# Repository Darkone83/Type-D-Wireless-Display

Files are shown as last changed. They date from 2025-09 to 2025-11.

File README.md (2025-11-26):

# Type-D Wireless Display

<div align=center>
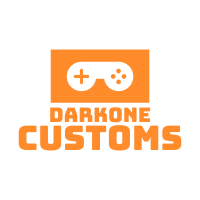
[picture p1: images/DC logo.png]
  
  
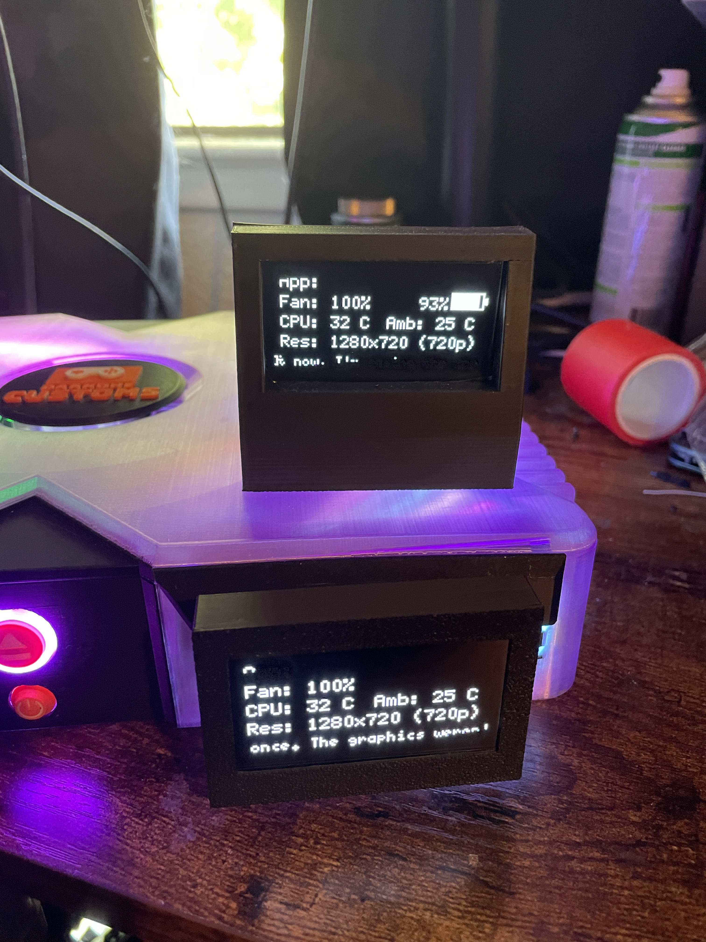
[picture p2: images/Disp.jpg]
  
</div>



A tiny OLED “status screen” for original Xbox setups (and other sources), driven over Wi‑Fi/UDP.  
Shows a main system summary, a dense second page, a health page, and an optional weather page, and insignia leaderboard page.
Designed for the Waveshare 2.42″ SSD1309 I²C panel (128×64), with added experimental support for US2066 OLED displays.
A Type D Expansion unit is required for these displays to properly work and display data. See more info <a href="https://github.com/Darkone83/Type-D/tree/main/EXP%20Src">Here</a>. To display the App name, the XBMC4Gamers script for the Type D Expansion unit is required.

---

## ✨ Features

- **Four screens** that auto-rotate:
  - **MAIN** – App name, fan %, CPU °C, ambient °C. Battery widget appears if a LC709203F fuel gauge is found.
  - **SECOND** – Tray state, AV type, encoder chip, guessed Xbox version, serial, MAC, region.
  - **HEALTH** – Wi‑Fi RSSI (with quality label), free heap, IP address.
  - **WEATHER** *(optional)* – Location header, big temp, condition text, humidity & wind.
  - **INSIGNIA** - Will display insignia leaderboard info when a compatible game is selected.
- **Inactivity policy (no “STALE”)**
  - Before any UDP data: full-screen boot logo only.
  - No UDP for **2 min**: show boot logo.
  - No UDP for **5 min**: bouncing “Sleeping…” screensaver.
  - Any UDP packet instantly cancels saver and resumes the carousel.
- **Smooth transitions** – slide-in left/right between screens.
- **Quote ticker** on MAIN with periodic rotation.
- **Web setup portal** (captive portal) for Wi‑Fi + Weather settings.
- **mDNS**: `http://typeddisp.local/` (when joined to your LAN).

---

## 📱 Get the App

Download on the App Store (https://apps.apple.com/us/app/type-d-viewer/id6755620952)

Download the **Type D Viewer** app for iOS to view live telemetry data from your XBOX.

---

## 🧰 Required Hardware

### Desktop build
- **ESP32‑S3**: Waveshare ESP32-S3 Zero or compatable. <a href="https://www.aliexpress.us/item/3256808233319699.html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">AliExpress (Clone)</a>, <a href="https://www.amazon.com/dp/B0CHYHGYRH?th=1">Amazon</a>.
- **Waveshare 2.42″ OLED**. <a href="https://www.waveshare.com/2.42inch-oled-module.htm">WaveShare</a>, <a href="https://www.amazon.com/dp/B0CM3RHMGP">Amazon</a>.
- *(Optional)* **LC709203F** fuel gauge (Adafruit breakout works great). <a href="https://www.adafruit.com/product/4712">Adafruit</a>.
- *(Optional)* LiPo pack if you want the battery widget to show %/voltage. <a href="https://www.adafruit.com/product/1781">Adafruit</a>.
- *Power Switches*: <a href="https://www.amazon.com/dp/B0DR2DPW59?th=1">Amazon</a>
- *Screws*: 4x 2mm x 4mm Pan head screws.

### Controller port build
- **ESP32‑S3**: Waveshare ESP32-S3 Zero or compatable. <a href="https://www.aliexpress.us/item/3256808233319699.html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">AliExpress (Clone)</a>, <a href="https://www.amazon.com/dp/B0CHYHGYRH?th=1">Amazon</a>.
- **Waveshare 2.42″ OLED**. <a href="https://www.waveshare.com/2.42inch-oled-module.htm">WaveShare</a>, <a href="https://www.amazon.com/dp/B0CM3RHMGP">Amazon</a>.
- **2 Caps**: 1x 100uF, 1X 10uF
- **Sacrificial OG XBOX dongle**: Needed to actually interface with the xbox controller port for power. <a href="https://www.aliexpress.us/item/3256803253950796.html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">AliExpress</a>
- **Picoblade Wiring kit:** <a href="https://www.amazon.com/1-25mm-Connectors-Pre-Crimped-Pixhawk-Silicone/dp/B07S18D3RN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">Amazon</a>, tou will need to the the 7p connectors.

---

## Purchase options:

Controller port kit: <a href="https://www.darkonecustoms.com/store/p/type-d-wireless-oled-kit">Darkone Customs</a>

---

### Wiring (I²C bus shared by OLED + LC709203F)

| Signal | ESP32‑S3 Pin | OLED | LC709203F |
|---:|:---|:-----|:---|
| SDA | **GPIO 6** | SDA  | SDA |
| SCL | **GPIO 7** | SCL  | SCL |
| RST | **GPIO 8** | RST  | |
| 3V3 | 3V3 | VCC  | VIN |
| GND | GND | GND  | GND |

---

## 🧪 Building

### Hardware:

#### Preparation:

Display needs the 2 0ohm resistors swapped from SPI position to the I2C position. If installing in the controller port shell, the pin header will need to be desoldered

#### Desktop Build:

For the desktop case, it's recommended to use a 18650 cell; other cells may work, but haven't been tested.

Images:

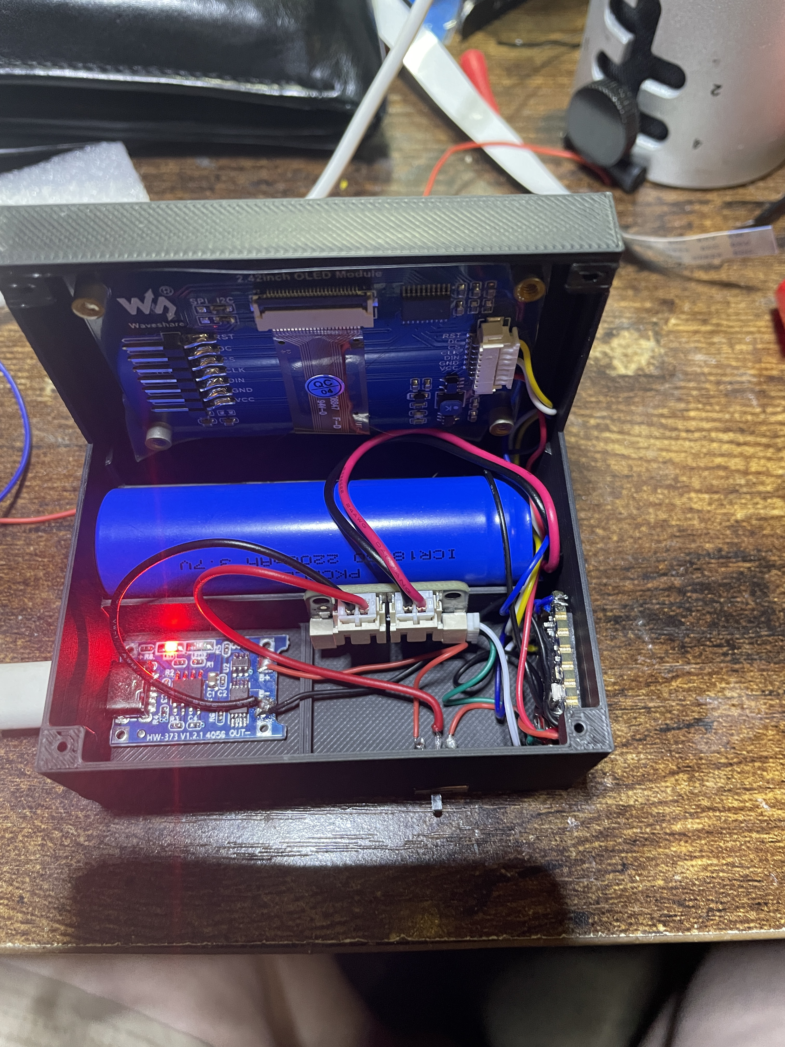
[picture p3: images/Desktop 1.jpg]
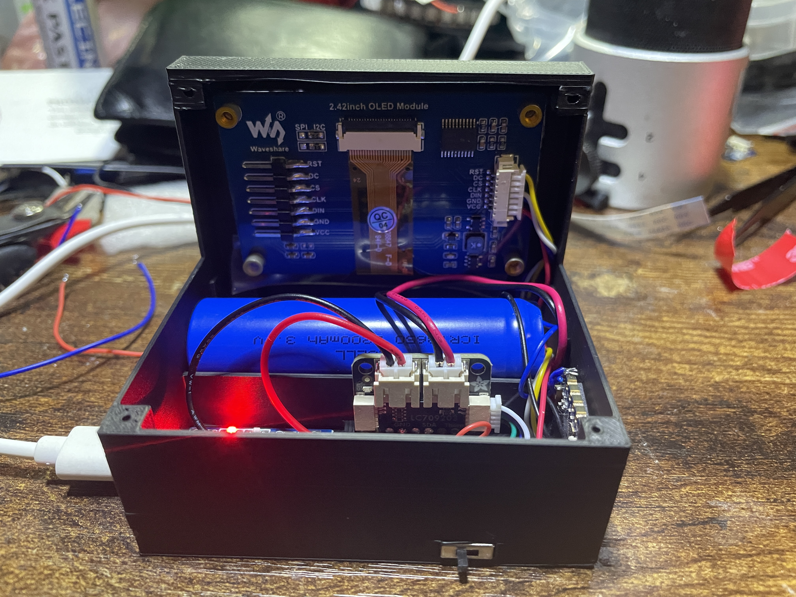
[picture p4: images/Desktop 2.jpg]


#### Controller Port:

Use some double-sided adhesive to assist with securing the display to the case. You will also need the adhesive for either the PCB installation or bare devboard installation.

Keep wire runs as short as possible. For the controller port connector, ensure it's flush with the rear of the case. Clearance is tight; test fit often during installation. 

If installing with a bare dev board, review the images for capacitor installation. The 100uF cap should be attached to the dev board, and the 10uF cap should be placed on the OLED's power pins. 

If installing the PCB, you will likely need to create your own wiring harness. View pinouts below

Images:



Note: Images shown are from development builds

### Pinouts:

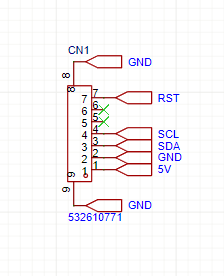
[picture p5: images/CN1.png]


---

## Software prep:

#### Web Flasher: 

### Arduino IDE
1. Install **ESP32** board support (ESP32‑S3 enabled).
2. Libraries:
   - **U8g2**
   - **ESP Async WebServer** (+ **AsyncTCP** for ESP32)
   - **Adafruit LC709203F**
   - **ArduinoJson**
3. Open the project, confirm I²C pins, then upload.

---

## 🚀 First Boot

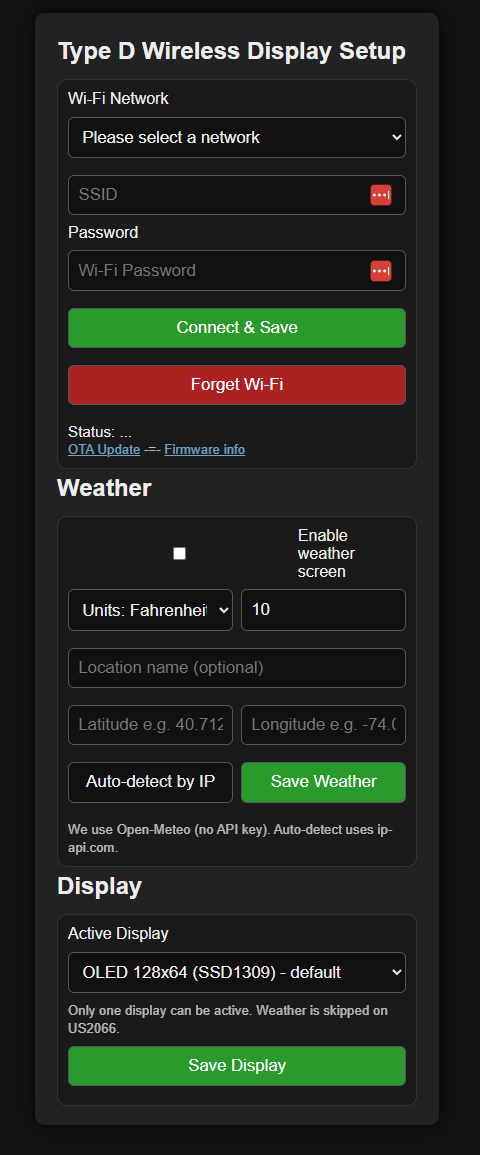
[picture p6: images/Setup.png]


1. Power the device. It boots into **AP+STA** and opens the portal:
   - SSID: **Type D Wireless Display Setup**
2. Visit any page (captive portal) or go to `http://192.168.4.1/`.
3. Select your Wi‑Fi, click **Connect & Save**.
4. (Optional) On the Weather card:
   - Check **Enable weather**, choose units, set **Refresh** minutes.
   - Enter **lat/lon** or click **Auto‑detect**.
   - Save.
5. When connected to your LAN, try `http://typeddisp.local/`.

> You should see the **boot logo** until the first UDP packets arrive.

---

## 🔍 Troubleshooting

- **Only boot logo, never changes**  
  No UDP is being received. Verify your sender IP/ports (see `udp_typed.h`) and that the device is on the same network.
- **Goes to “Sleeping…” even though I’m sending data**  
  Make sure the sender actually emits packets within 5 minutes and that they match one of the **A/B/C** ports. The inactivity logic is based on “last packet time”, not packet contents.
- **Weather never shows**  
  Enable it in the portal, provide a valid lat/lon (or use Auto‑detect), and ensure the device has Internet access.
- **Battery widget doesn’t appear**  
  LC709203F not detected on I²C 0x0B, or warm‑up not finished. Check wiring and that the APA define matches your pack (optional but recommended).

---

## 🗺️ Roadmap

- Scroll‑in place for long resolution strings.
- Optional iconography for weather (we currently use text‑only for reliability).

---

## 📜 License & Credits

- Code: MIT (unless otherwise noted in source files).
- Weather: https://open-meteo.com (no key). IP geolocation: https://ip-api.com.
- Fonts & display driver: https://github.com/olikraus/u8g2
- Fuel gauge: Adafruit LC709203F library.

---

## 🙌 Contributing

PRs welcome! Please include:
- Your board/panel variant and wiring
- Repro steps or packet samples if you’re touching UDP
- Before/after screenshots for UI tweaks

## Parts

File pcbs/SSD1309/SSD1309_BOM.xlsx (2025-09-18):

No. | Quantity | Comment | Designator | Footprint | Value | Manufacturer Part | Manufacturer | Supplier Part | Supplier
1 | 1 | 220uF | C1 | C1206 | 220uF | GRM31CR60J227ME11L | muRata(村田) | C412252 | LCSC
2 | 1 | 10uF | C2 | C0603 | 10uF | CL10A106KP8NNNC | SAMSUNG(三星) | C19702 | LCSC
3 | 1 | 532610771 | CN1 | CONN-SMD_532610771 |  | 532610771 | MOLEX | C505276 | LCSC
4 | 1 | ESP32-S3-Zero | U1 | COMM-SMD_18P-P2.54-L23.5-W18.0-TL |  | ESP32-S3-Zero |  | C9900152785 | LCSC

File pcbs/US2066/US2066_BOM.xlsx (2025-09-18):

No. | Quantity | Comment | Designator | Footprint | Value | Manufacturer Part | Manufacturer | Supplier Part | Supplier
1 | 5 | Test-Point | 5V,GND,TP1,TP2,TP3 | Test-Point-0.5mm
2 | 2 | 1uF | C1,C2 | C0402 | 1uF | CL05A105KO5NNNC | SAMSUNG(三星) | C29266 | LCSC
3 | 1 | CBM100505U201T | FB1 | L0402 |  | CBM100505U201T | FH(风华) | C394402 | LCSC
4 | 1 | ESP32-S3-Zero | U1 | COMM-SMD_18P-P2.54-L23.5-W18.0-TL |  | ESP32-S3-Zero |  | C9900152785 | LCSC
5 | 1 | XC6227C331MR-G | U4 | SOT-25-5 |  | XC6227C331MR-G | TOREX(特瑞仕) | C216640 | LCSC

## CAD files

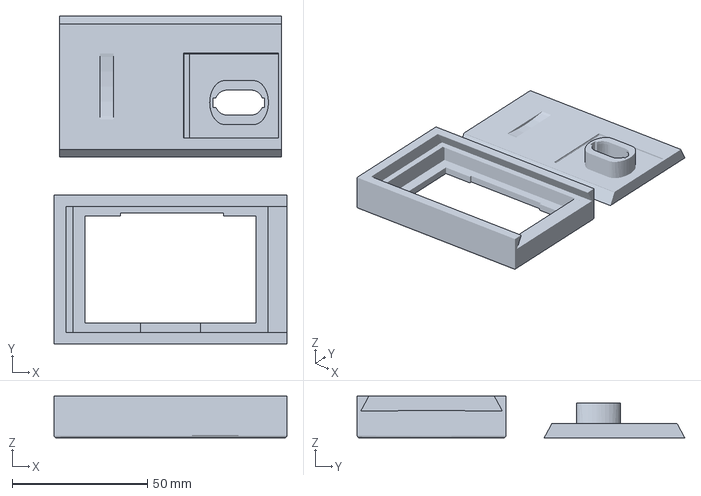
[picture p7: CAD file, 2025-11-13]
contrib/stl/aliexpress 2.42 oled slide version.3mf
86.0 x 121.0 x 15.5 mm

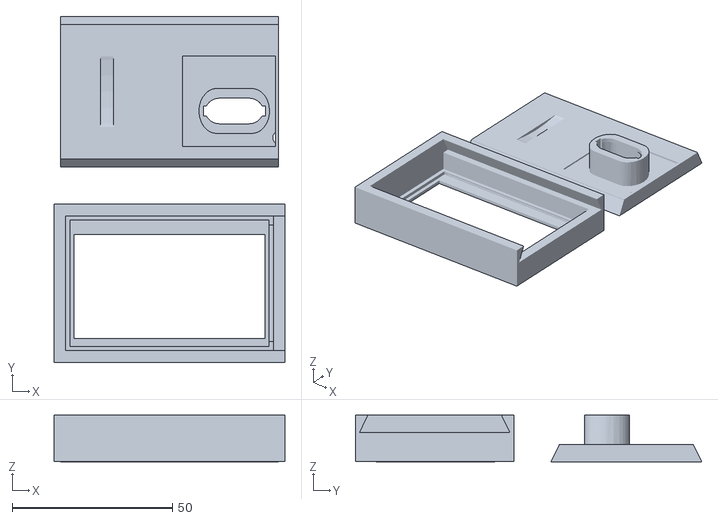
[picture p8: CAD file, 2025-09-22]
STL/Shell Controller Port.stl
72.0 x 108.0 x 14.5

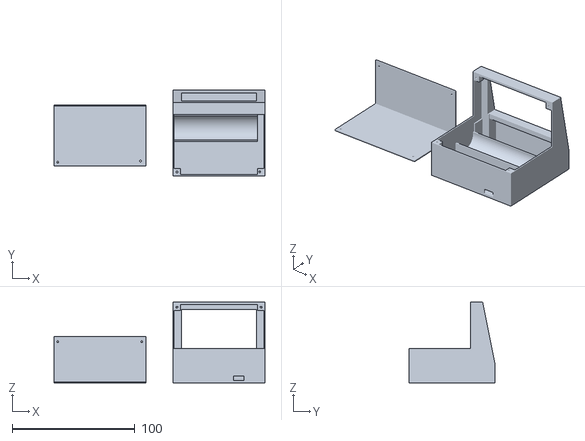
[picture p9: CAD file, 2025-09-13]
STL/Shell Desktop.stl
172.0 x 70.0 x 66.0

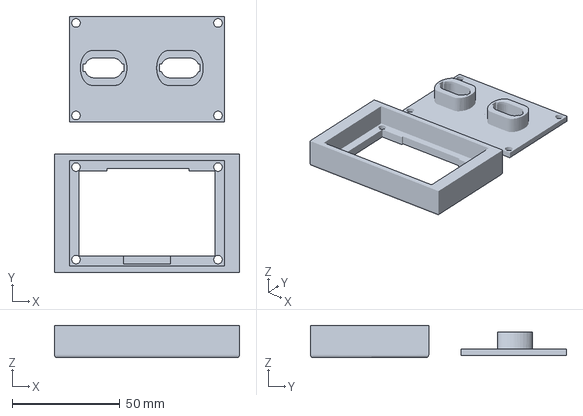
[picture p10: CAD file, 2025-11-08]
contrib/stl/2.42 aliexpress screw case.3mf
86.0 x 119.0 x 15.0 mm

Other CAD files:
contrib/stl/2.42 aliexpress screw case.stl
contrib/stl/aliexpress 2.42 oled slide version.stl

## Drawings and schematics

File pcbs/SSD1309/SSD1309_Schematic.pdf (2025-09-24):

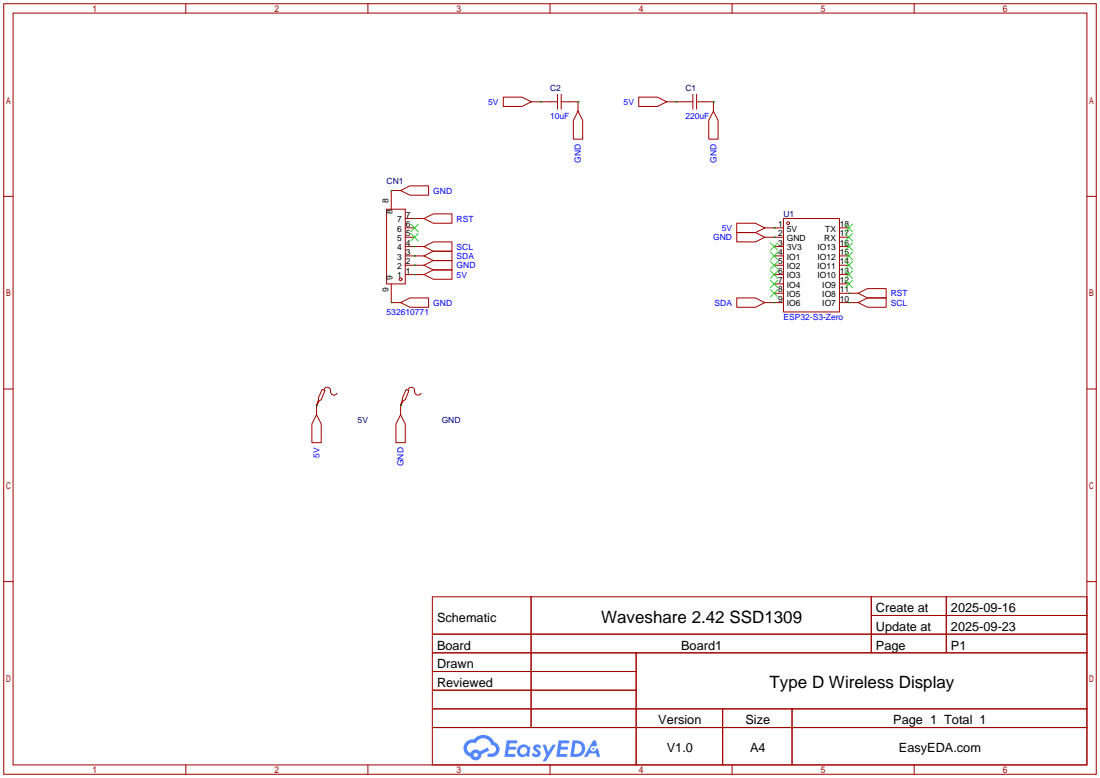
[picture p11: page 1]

Schematic | Waveshare 2.42 SSD1309 | Create at | 2025-09-16

Update at | 2025-09-23

Board | Board1 | Page | P1
Drawn | | Type D Wireless Display
Reviewed

Version | Size | Page 1 Total 1
V1.0 | A4 | EasyEDA.com

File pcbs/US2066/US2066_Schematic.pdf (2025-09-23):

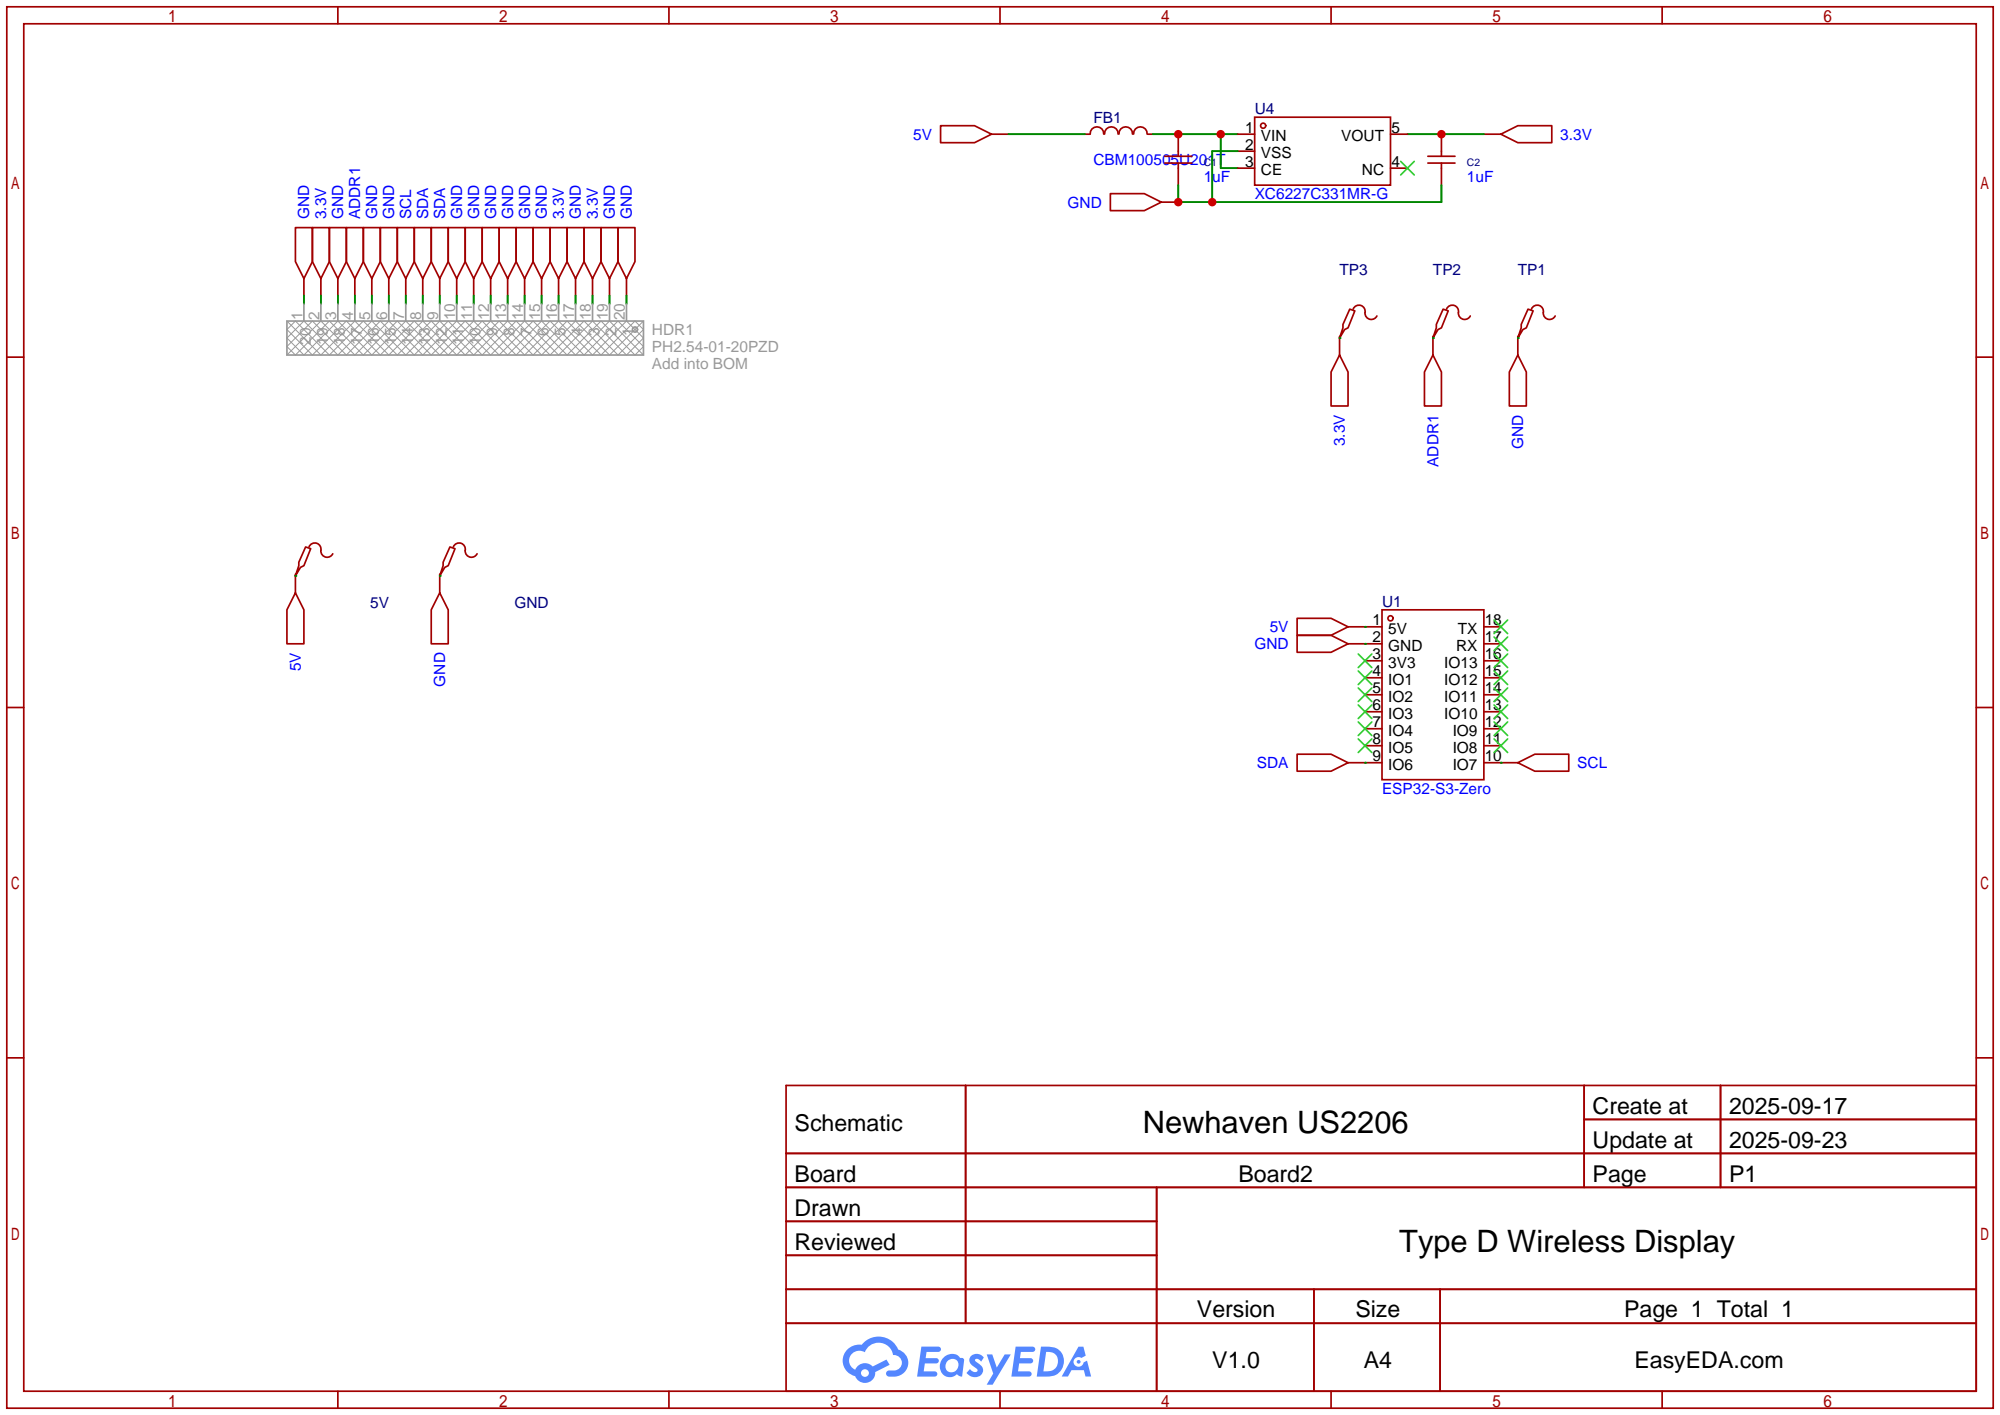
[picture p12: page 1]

Schematic | Newhaven US2206 | Create at | 2025-09-17

Update at | 2025-09-23

Board | Board2 | Page | P1
Drawn | | Type D Wireless Display
Reviewed

Version | Size | Page 1 Total 1
V1.0 | A4 | EasyEDA.com

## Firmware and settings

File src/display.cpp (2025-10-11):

// display.cpp — Type-D Wireless Display (SSD1309) with ConsoleMods-based Xbox version guessing
// Screens: MAIN / SECOND / HEALTH / WEATHER
// - MAIN: rows + scrolling game quote; new quote on MAIN entry & every 60s
//         + Battery widget on the Fan row (right-justified) if LC709203F is detected
// - SECOND: dense info (Tray/AV/Xbox/Encoder/Serial/MAC/Region)
// - HEALTH: simplified, text-only (WiFi RSSI, Free memory, IP)
// - WEATHER: icon + temp + cond, humidity, wind (Open-Meteo, keyless)
// Inactivity policy (final):
//   - Show ONLY the DC logo (full-screen) before first MAIN packet.
//   - If NO packets (A/B/C) for 2 min -> show DC logo (searching).
//   - If NO packets (A/B/C) for 5 min -> screensaver (bouncing “Sleeping...”).
//   - On any packet -> exit saver and resume.
//   - We NEVER draw “STALE”.
// Transitions: slide-in left/right only.

#include "display.h"
#include <U8g2lib.h>
#include "udp_typed.h"
#include <WiFi.h>
#include <esp_system.h>
#include <Arduino.h>
#include <ctype.h>
#include <string.h>
#include <math.h>          // isnan(), fabsf()
#include <Preferences.h>

// --- Boot glyph (dc_logo.h) ---
#include "dc_logo.h"

// --- Fuel gauge (Adafruit LC709203F) ---
#include <Adafruit_LC709203F.h>

// --- Weather fetch (Open-Meteo) ---
#include <HTTPClient.h>
#include <WiFiClientSecure.h>
#include <ArduinoJson.h>

// --- Insignia 5th screen (NEW) ---
#include "insignia.h"

namespace TypeDDisplay {

// ===== Module state =====
static U8G2* g = nullptr;
static bool g_dbg = true;

// Hold times
static uint32_t HOLD_MAIN_MS    = 15000;
static uint32_t HOLD_SECOND_MS  =  5000;
static uint32_t HOLD_HEALTH_MS  =  5000;
static uint32_t HOLD_WEATHER_MS =  7000;   // NEW: weather screen hold
static uint32_t HOLD_INSIGNIA_MS= 12000;   // NEW: insignia screen hold

// Draw cadence
static const  uint32_t DRAW_INTERVAL_MS = 200;
static        uint32_t lastDraw = 0;

// Screens
enum class Screen : uint8_t { WAITING=0, MAIN, SECOND, HEALTH, WEATHER, INSIGNIA };
static Screen   cur = Screen::WAITING;
static uint32_t nextSwitchAt = 0;

// Inactivity thresholds (ANY UDP)
static const uint32_t NO_PACKET_LOGO_MS  = 120000UL;
static const uint32_t NO_PACKET_SAVER_MS = 300000UL;

// Track what we’ve ever seen
static bool     everAnyPacket = false;
static bool     haveMain = false;
// Proper timestamp of last packet arrival (fixes false “Sleeping...”)
static uint32_t lastAnyAt = 0;

// Transitions
enum class Xition : uint8_t { NONE=0, SLIDE_IN_RIGHT, SLIDE_IN_LEFT };
static Xition nextXition = Xition::NONE;

// ===== Data caches from UDP =====
static struct {
  bool have = false;
  int32_t fan = 0;
  int32_t cpu_c = 0;
  int32_t amb_c = 0;
  char app[33] = {0};
} MAIN;

static struct {
  bool have = false;
  int32_t tray = -1;
  int32_t av   = -1;
  int32_t xboxver = -1;
  int32_t enc  = -1;
  int32_t width = 0, height = 0;
} EXT;

static struct {
  bool have = false;
  String serial;
  String mac;
  String region;
} EE;

// ===== Fuel gauge (LC709203F) =====
static Adafruit_LC709203F lc;
static bool lc_ok = false;
static bool lc_tried = false;
static uint32_t lc_lastTry = 0;
static const uint32_t LC_RETRY_MS = 5000;

// Shown on-screen (smoothed)
static float lc_pct = NAN;
static float lc_v   = NAN;
static uint32_t lc_lastRead = 0;
static const uint32_t LC_READ_MS = 3000;

// Accuracy/consistency helpers
static uint32_t lc_ok_since = 0;            // when gauge first came up
static const uint32_t LC_WARMUP_MS   = 1500; // initial settle window
static int lc_warmup_reads           = 0;    // also require N good reads
static const int LC_WARMUP_READS     = 3;

static const float LC_ALPHA_P        = 0.25f; // EMA factor for percent smoothing
static const float LC_ALPHA_V        = 0.30f; // EMA factor for voltage smoothing
static const float LC_MAX_STEP_P     = 6.0f;  // clamp % step per sample
static const float LC_MAX_JUMP_V     = 0.12f; // reject raw V jumps >120 mV/read
static const float LC_MAX_JUMP_P     = 12.0f; // reject raw % jumps >12%/read
static const float LC_BLEND_W        = 0.60f; // weight for library % vs OCV % (0..1)
static float lc_v_filt = NAN;                // filtered voltage
static float last_p_raw = NAN, last_v_raw = NAN;

// Voltage→% (very rough LiPo curve, linear between points)
static float pctFromVoltage(float v) {
  if (v <= 3.30f) return 0.f;
  if (v >= 4.20f) return 100.f;
  struct P { float v, p; };
  const P pts[] = { {4.20,100},{4.08,95},{3.98,90},{3.92,85},{3.86,80},{3.80,75},{3.75,70},{3.70,60},{3.65,50},{3.60,45},{3.55,35},{3.50,25},{3.45,15},{3.40,8},{3.30,0} };
  for (size_t i=1;i<sizeof(pts)/sizeof(pts[0]);++i) if (v >= pts[i].v) {
    const float t = (v - pts[i].v) / (pts[i-1].v - pts[i].v);
    return pts[i].p + t * (pts[i-1].p - pts[i].p);
  }
  return 50.f; // shouldn't reach
}

static inline bool plausibleV(float v) { return (!isnan(v) && v > 3.0f && v < 5.5f); }
static inline bool plausibleP(float p) { return (!isnan(p) && p >= 0.f  && p <= 100.f); }

static void resetGaugeFilters() {
  lc_pct = NAN;
  lc_v = lc_v_filt = NAN;
  last_p_raw = last_v_raw = NAN;
  lc_warmup_reads = 0;
}

// NOTE: We do NOT use a thermistor. No thermistor config calls are made.
static void maybeInitGauge() {
  if (lc_ok) return;
  uint32_t now = millis();
  if (lc_tried && (now - lc_lastTry < LC_RETRY_MS)) return;

  lc_tried = true;
  lc_lastTry = now;

  // Uses default address 0x0B on the existing Wire bus
  if (lc.begin()) {
    lc_ok = true;
    lc_ok_since = millis();
    resetGaugeFilters();

    // If you define a known pack size at build-time, it will be applied.
    #if defined(LC709203F_APA_2200MAH)
      lc.setPackSize(LC709203F_APA_2200MAH);
    #elif defined(LC709203F_APA_2000MAH)
      lc.setPackSize(LC709203F_APA_2000MAH);
    #elif defined(LC709203F_APA_2500MAH)
      lc.setPackSize(LC709203F_APA_2500MAH);
    #endif

    // Keep default temperature behavior (internal IC method). No thermistor used.

    #ifdef LC709203F_POWER_OPERATE
      lc.setPowerMode(LC709203F_POWER_OPERATE);
    #endif
    if (g_dbg) Serial.println("[DISPLAY] LC709203F detected + configured (no thermistor)");
  } else {
    lc_ok = false;
    if (g_dbg) Serial.println("[DISPLAY] LC709203F not found (will retry)");
  }
}

static void updateGaugeReading() {
  if (!lc_ok) return;
  uint32_t now = millis();
  if (now - lc_lastRead < LC_READ_MS) return;
  // give the IC a moment after power-up to stabilize OCV estimate
  if (lc_ok_since && (now - lc_ok_since < LC_WARMUP_MS)) return;
  lc_lastRead = now;

  float p_raw = lc.cellPercent();  // library estimate
  float v_raw = lc.cellVoltage();  // measured voltage

  // Basic plausibility
  if (!plausibleV(v_raw)) v_raw = NAN;
  if (!plausibleP(p_raw)) p_raw = NAN;

  // Reject sudden jumps (vs last raw)
  if (plausibleV(v_raw) && plausibleV(last_v_raw)) {
    if (fabsf(v_raw - last_v_raw) > LC_MAX_JUMP_V) v_raw = NAN;
  }
  if (plausibleP(p_raw) && plausibleP(last_p_raw)) {
    if (fabsf(p_raw - last_p_raw) > LC_MAX_JUMP_P) p_raw = NAN;
  }

  // Update last_raw if valid
  if (!isnan(v_raw)) last_v_raw = v_raw;
  if (!isnan(p_raw)) last_p_raw = p_raw;

  // Voltage EMA
  if (!isnan(v_raw)) {
    if (isnan(lc_v_filt)) lc_v_filt = v_raw;
    else lc_v_filt += LC_ALPHA_V * (v_raw - lc_v_filt);
    lc_v = lc_v_filt; // expose filtered V for UI/debug
  }

  // Warm-up: require a few valid samples total before showing %
  if (lc_warmup_reads < LC_WARMUP_READS) {
    if (!isnan(v_raw) || !isnan(p_raw)) lc_warmup_reads++;
    if (lc_warmup_reads < LC_WARMUP_READS) return;
  }

  // Stable % estimate:
  // - Prefer library percent when sane
  // - Blend with OCV-derived percent from filtered voltage
  float p_est = NAN;
  const bool have_lib = plausibleP(p_raw);
  const bool have_v   = plausibleV(lc_v_filt);
  float p_ocv = have_v ? pctFromVoltage(lc_v_filt) : NAN;

  if (have_lib && have_v)      p_est = LC_BLEND_W * p_raw + (1.f - LC_BLEND_W) * p_ocv;
  else if (have_lib)           p_est = p_raw;
  else if (have_v)             p_est = p_ocv;

  // Smooth + clamp steps + monotonic guard
  if (!isnan(p_est)) {
    if (isnan(lc_pct)) {
      lc_pct = p_est;
    } else {
      float delta = p_est - lc_pct;

      // Monotonic guard: if voltage clearly falling (>30 mV step), don’t let % rise
      if (!isnan(last_v_raw) && !isnan(lc_v_filt) && (last_v_raw - lc_v_filt) > 0.03f && delta > 0) {
        delta = 0.f;
      }

      if (delta >  LC_MAX_STEP_P) delta =  LC_MAX_STEP_P;
      if (delta < -LC_MAX_STEP_P) delta = -LC_MAX_STEP_P;
      lc_pct += LC_ALPHA_P * delta;
    }
    // keep inside [0,100]
    if (lc_pct < 0.f)   lc_pct = 0.f;
    if (lc_pct > 100.f) lc_pct = 100.f;
  }

  if (g_dbg) {
    if (!isnan(lc_pct) && !isnan(lc_v_filt))
      Serial.printf("[DISPLAY] batt=%.1f%% (Vf=%.3f V)%s%s\n",
                    lc_pct, lc_v_filt,
                    have_lib ? "" : " [no-lib%]",
                    (have_v && have_lib ? " [blend]" : ""));
    else if (!isnan(lc_v_filt))
      Serial.printf("[DISPLAY] batt=--%% (Vf=%.3f V)\n", lc_v_filt);
    else
      Serial.printf("[DISPLAY] batt=-- (no gauge)\n");
  }
}

// ===== WEATHER =====
static struct {
  bool   enabled = false;  // portal toggle
  char   units   = 'F';    // 'F' or 'C'
  double lat     = NAN;    // from portal or IP geolocate (stored in Preferences by portal)
  double lon     = NAN;
  uint32_t refresh_ms = 10UL * 60UL * 1000UL; // default 10 min

  bool   ok    = false;    // we have valid data to show
  uint32_t last_fetch = 0;

  // data
  float  temp = NAN;     // degC/degF depending on units
  int    rh   = -1;      // %
  float  wind = NAN;     // mph/kph approx
  int    code = -1;      // weather_code
  char   place[32] = {0}; // optional name (from prefs), else coords
} W;

// (load prefs) — read once at begin(); portal writes them into "weather" namespace
static void loadWeatherPrefs() {
  Preferences prefs;
  if (!prefs.begin("weather", true)) return;

  W.enabled = prefs.getBool("enabled", false);
  String u = prefs.getString("units", "F");
  W.units = (u.length() && (u[0]=='C' || u[0]=='c')) ? 'C' : 'F';
  W.lat = prefs.getDouble("lat", NAN);
  W.lon = prefs.getDouble("lon", NAN);
  int refMin = prefs.getInt("refresh", 10);
  if (refMin < 1) refMin = 1; if (refMin > 120) refMin = 120;
  W.refresh_ms = (uint32_t)refMin * 60UL * 1000UL;
  String nm = prefs.getString("name", "");
  nm.toCharArray(W.place, sizeof(W.place));
  prefs.end();

  if (g_dbg) {
    Serial.printf("[WEATHER] enabled=%d units=%c lat=%.5f lon=%.5f refresh=%lus name='%s'\n",
                  (int)W.enabled, W.units, W.lat, W.lon, W.refresh_ms/1000UL, W.place);
  }
}


// choose biggest temp font that fits in maxW
static const uint8_t* pickTempFont(const char* text, int maxW) {
  const uint8_t* candidates[] = {
    u8g2_font_logisoso24_tf,
    u8g2_font_logisoso20_tf,
    u8g2_font_logisoso16_tf
  };
  for (auto f : candidates) {
    g->setFont(f);
    if (g->getStrWidth(text) <= maxW) return f;
  }
  return u8g2_font_logisoso16_tf;
}

// choose best header font that fits in maxW
static const uint8_t* pickHeaderFont(const String& s, int maxW) {
  g->setFont(u8g2_font_6x12_tf);
  if (g->getStrWidth(s.c_str()) <= maxW) return u8g2_font_6x12_tf;
  return u8g2_font_5x8_tf;
}

static const char* labelForCode(int code) {
  if (code == 0) return "Clear";
  if (code==1) return "Mostly clear";
  if (code==2) return "Partly cloudy";
  if (code==3) return "Overcast";
  if (code==45 || code==48) return "Fog";
  if (code==51 || code==53 || code==55) return "Drizzle";
  if (code==56 || code==57) return "Frz drizzle";
  if (code==61 || code==63 || code==65) return "Rain";
  if (code==66 || code==67) return "Frz rain";
  if (code==71 || code==73 || code==75) return "Snow";
  if (code==77) return "Snow grains";
  if (code==80 || code==81 || code==82) return "Showers";
  if (code==85 || code==86) return "Snow shwrs";
  if (code==95) return "Thunder";
  if (code==96 || code==99) return "T-storm hail";
  return "—";
}

static bool fetchWeatherNow() {
  if (!W.enabled) return false;
  if (!WiFi.isConnected()) return false;
  if (isnan(W.lat) || isnan(W.lon)) return false;

  // Build Open-Meteo URL
  String url = "https://api.open-meteo.com/v1/forecast?latitude=" + String(W.lat, 5) +
               "&longitude=" + String(W.lon, 5) +
               "&current=temperature_2m,weather_code,relative_humidity_2m,wind_speed_10m";
  if (W.units == 'F') {
    url += "&temperature_unit=fahrenheit&windspeed_unit=mph";
  } else {
    url += "&temperature_unit=celsius&windspeed_unit=kmh";
  }

  WiFiClientSecure ssl;
  ssl.setInsecure();       // keep it simple; you can pin CA later
  HTTPClient http;
  http.setTimeout(4000);

  if (!http.begin(ssl, url)) {
    if (g_dbg) Serial.println("[WEATHER] http.begin failed");
    return false;
  }
  int code = http.GET();
  if (code != 200) {
    if (g_dbg) Serial.printf("[WEATHER] GET failed: %d\n", code);
    http.end();
    return false;
  }
  String body = http.getString();
  http.end();

  // Parse small JSON
  StaticJsonDocument<1024> doc;
  DeserializationError err = deserializeJson(doc, body);
  if (err) {
    if (g_dbg) Serial.printf("[WEATHER] JSON error: %s\n", err.c_str());
    return false;
  }
  JsonObject cur = doc["current"];
  if (cur.isNull()) return false;

  W.temp = cur["temperature_2m"] | NAN;
  W.rh   = cur["relative_humidity_2m"] | -1;
  W.wind = cur["wind_speed_10m"] | NAN;
  W.code = cur["weather_code"] | -1;
  W.ok   = !isnan(W.temp) && (W.code >= 0);
  W.last_fetch = millis();

  if (g_dbg) {
    Serial.printf("[WEATHER] t=%.1f %c rh=%d%% wind=%.1f code=%d\n",
                  W.temp, W.units, W.rh, W.wind, W.code);
  }
  return W.ok;
}

// ===== Quotes =====
static const char* kQuotes[] = {
  "I don't need to get a life. I'm a gamer - I have lots of lives.",
  "I went outside once. The graphics weren't that good.",
  "I paused my game to be here.",
  "Everything is under control.",
  "Eat. Sleep. Game. Repeat.",
  "It's-a me, Mario!",
  "Escape reality and play games.",
  "Tips on how to talk to someone when they're gaming: don't.",
  "When life gets hard, it means you just leveled up.",
  "I can't hear you. I'm gaming.",
  "Not now. I'm saving the world.",
  "Reality is broken but game designers can fix it.",
  "Life is a video game. You always get zapped in the end.",
  "Finish him!",
  "Failure doesn't mean game over. Try again with more experience.",
  "Just one more game.",
  "Don't wish it were easier. Wish you were better.",
  "Don't play the game. Win it.",
  "One day my mom will understand that online games cannot be paused.",
  "That moment you finish a game and don't know what to do with your life."
};
static const int kQuoteCount = sizeof(kQuotes)/sizeof(kQuotes[0]);

static int   qIndex = 0;
static int   qScroll = 0;
static uint32_t qLastStep = 0;
static const uint32_t Q_STEP_MS = 50;
static const int Q_PAD = 24;

static uint32_t qLastChange = 0;
static const uint32_t Q_ROTATE_MS = 60000UL;

static inline void pickRandomQuote() {
  uint32_t r = (uint32_t)esp_random();
  qIndex = (int)(r % (uint32_t)kQuoteCount);
  qScroll = 0;
  qLastStep = 0;
  qLastChange = millis();
  if (g_dbg) Serial.printf("[DISPLAY] Quote -> #%d\n", qIndex);
}

// ===== Labels & helpers =====
static const char* trayLabel(int v) {
  switch (v & 0xFF) { case 0x00: return "Closed"; case 0x01: return "Open"; case 0x02: return "Busy"; default: return "Unknown"; }
}
static const char* encLabel(int v) {
  switch (v & 0xFF) { case 0x45: return "Conexant"; case 0x6A: return "Focus"; case 0x70: return "Xcalibur"; default: return "Unknown"; }
}
static const char* xboxVerFromCode(int v) {
  switch (v & 0xFF) {
    case 0: return "v1.0"; case 1: return "v1.1"; case 2: return "v1.2";
    case 3: return "v1.3"; case 4: return "v1.4"; case 5: return "v1.5";
    case 6: return "v1.6"; default: return "Not reported";
  }
}
static bool av_is_hd(int v) { v &= 0xFF; return (v == 0x01) || (v == 0x02) || ((v & 0x0E) == 0x0A); }
static const char* avLabel(int v) {
  v &= 0xFF;
  switch (v) {
    case 0x00: return "SCART"; case 0x01: return "HDTV (Component)"; case 0x02: return "VGA"; case 0x03: return "RFU";
    case 0x04: return "Advanced (S-Video)"; case 0x06: return "Standard (Composite)"; case 0x07: return "Missing/Disconnected";
  }
  switch (v & 0x0E) {
    case 0x00: return "None/Disconnected"; case 0x02: return "Standard (Composite)";
    case 0x06: return "Advanced (S-Video)"; case 0x0A: return "HDTV (Component)"; case 0x0E: return "SCART";
  }
  return "Unknown";
}
static String sdSystemFromH(int h) { return (h >= 570) ? "PAL" : "NTSC"; }
static String modeFromRes(int w, int h, int avraw) {
  if (w >= 1900 && h == 1080) return "1080i";
  if (w == 1280 && h == 720)  return "720p";
  if ((w == 640 || w == 704 || w == 720) && h == 480) return av_is_hd(avraw) ? "480p" : "480i";
  if (w == 720 && h == 576)   return av_is_hd(avraw) ? "576p" : "576i";
  return "";
}
static String fmtResLine() {
  if (!EXT.have || EXT.width <= 0 || EXT.height <= 0) return "—";
  String mode = modeFromRes(EXT.width, EXT.height, EXT.av);
  if (mode.length()) {
    if (mode.startsWith("480") || mode.startsWith("576")) mode += " " + sdSystemFromH(EXT.height);
    return String(EXT.width) + "x" + String(EXT.height) + " (" + mode + ")";
  }
  return String(EXT.width) + "x" + String(EXT.height);
}

// ===== ConsoleMods serial parsing and version guess =====
static bool parseSerialYWWFF(const String& s, int& outYear, int& outWeek, int& outFactory) {
  int len = s.length();
  int run = 0, end = -1;
  for (int i = len - 1; i >= 0; --i) {
    if (isdigit((unsigned char)s[i])) { run++; if (run == 5) { end = i + 5; break; } }
    else run = 0;
  }
  if (end < 0) return false;
  int start = end - 5;
  int Y   = s[start] - '0';
  int WW  = (s[start+1]-'0')*10 + (s[start+2]-'0');
  int FF  = (s[start+3]-'0')*10 + (s[start+4]-'0');
  if (WW < 1 || WW > 53) return false;
  outYear = 2000 + Y; outWeek = WW; outFactory = FF;
  return true;
}
static String versionFromYearWeek(int year, int week) {
  if (year == 2001) return "v1.0";
  if (year == 2002) { if (week <= 43) return "v1.0"; if (week <= 47) return "v1.1"; return "v1.2"; }
  if (year == 2003) { if (week <= 8)  return "v1.2"; if (week <= 30) return "v1.3"; return "v1.4"; }
  if (year == 2004) { if (week <= 10) return "v1.4"; if (week <= 37) return "v1.6"; return "v1.6b"; }
  if (year >= 2005) return "v1.6b";
  return "Not reported";
}
static String guessFromSerialAndEncoder(int encRaw, const String& serial) {
  int year=0, week=0, factory=0;
  bool ok = parseSerialYWWFF(serial, year, week, factory);
  const int enc = (encRaw & 0xFF);
  auto encSuggest = [&]() -> String {
    if (enc == 0x70) return "v1.6";
    if (enc == 0x6A) return "v1.4";
    if (enc == 0x45) return "v1.0–1.3";
    return "";
  };
  if (!ok) {
    String e = encSuggest();
    return e.length() ? e : "Not reported";
  }
  if (factory == 3)  return "v1.0"; // Hungary
  if (factory == 2)  return (year < 2002 || (year == 2002 && week < 44)) ? "v1.0" : "v1.1"; // Mexico
  String ywGuess = versionFromYearWeek(year, week);
  if (enc == 0x70) { if (year >= 2004 && week >= 38) return "v1.6b"; return "v1.6"; }
  if (enc == 0x6A) { if (ywGuess.startsWith("v1.0") || ywGuess.startsWith("v1.1") || ywGuess.startsWith("v1.2") || ywGuess.startsWith("v1.3")) return "v1.4"; }
  if (enc == 0x45) { if (ywGuess.startsWith("v1.4") || ywGuess.startsWith("v1.6")) return "v1.3"; }
  return ywGuess;
}
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
void loop() {
  if (!g) return;

  // Fuel gauge maintenance (init + periodic read)
  maybeInitGauge();
  updateGaugeReading();

  // Weather refresh cadence (non-blocking most of the time)
  if (W.enabled) {
    uint32_t noww = millis();
    if (W.last_fetch == 0 || noww - W.last_fetch >= W.refresh_ms) {
      fetchWeatherNow();
    }
  }

  // Ingest any new UDP packets (drain ring buffer)
  if (TypeDUDP::available()) onPacket();

  // Let Insignia advance timers regardless of current screen
  Insignia::tick();

  // Compute inactivity from ANY port (use our timestamp, not an "age" misinterpreted as a time)
  const uint32_t now = millis();
  const bool noAny5m = (everAnyPacket && lastAnyAt && (now - lastAnyAt >= NO_PACKET_SAVER_MS));
  const bool noAny2m = (everAnyPacket && lastAnyAt && (now - lastAnyAt >= NO_PACKET_LOGO_MS));

  // If we've never seen ANY packet, or MAIN hasn't arrived yet, show logo
  if (!everAnyPacket || !haveMain) {
    drawBootGlyph();
    return;
  }

  // Inactivity gating
  if (noAny5m) {
    if (!saverActive) startScreensaver();
    drawScreensaverFrame();
    return;
  }
  if (saverActive) stopScreensaver();
  if (noAny2m) { drawBootGlyph(); return; }

  // Normal screen scheduler
  if (cur == Screen::WAITING) {
    cur = Screen::MAIN;
    nextSwitchAt = now + holdFor(cur);
    pickRandomQuote();
    if (g_dbg) Serial.println("[DISPLAY] first MAIN -> MAIN");
    doTransition(cur);
    return;
  }

  if (now >= nextSwitchAt) {
    cur = nextScreen(cur);
    nextSwitchAt = now + holdFor(cur);
    if (cur == Screen::MAIN) pickRandomQuote();
    if (g_dbg) {
      const char* nm =
        (cur==Screen::MAIN)?"MAIN":
        (cur==Screen::SECOND)?"SECOND":
        (cur==Screen::HEALTH)?"HEALTH":
        (cur==Screen::WEATHER)?"WEATHER":"INSIGNIA";
      Serial.printf("[DISPLAY] switch -> %s\n", nm);
    }
    doTransition(cur);
    return;
  }

  if (cur == Screen::MAIN && (now - qLastChange >= Q_ROTATE_MS)) pickRandomQuote();

  if (now - lastDraw >= DRAW_INTERVAL_MS) {
    lastDraw = now;
    if      (cur == Screen::MAIN)     drawMainScreen(0);
    else if (cur == Screen::SECOND)   drawSecondScreen(0);
    else if (cur == Screen::HEALTH)   drawHealthScreen(0);
    else if (cur == Screen::WEATHER)  drawWeatherScreen(0);
    else                              Insignia::draw(g);
  }
}

} // namespace TypeDDisplay

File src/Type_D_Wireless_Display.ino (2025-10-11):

#include "wifimgr.h"
#include "led_stat.h"
#include "udp_typed.h"
#include "display.h"
#include "weather.h"
#include "insignia.h"

#include <Arduino.h>
#include <Wire.h>
#include <U8g2lib.h>
#include <WiFi.h>
#include <ESPmDNS.h>

// -------- Character OLED (US2066 20x4) --------
#include "us2066.h"
#include "us2066_view.h"

// -------- OLED (Waveshare 2.42" SSD1309 I2C @ 0x3D) --------
static const int PIN_SDA = 6;
static const int PIN_SCL = 7;
static const int PIN_RST = 9;   // SSD1309 RESET wired to GPIO 9

U8G2_SSD1309_128X64_NONAME2_F_HW_I2C u8g2(U8G2_R0, /* reset = */ PIN_RST);

// US2066 objects
US2066      charOled;
US2066View  charView;
bool        useUS2066 = false;

// ---- helpers to init US2066 path ----
static bool initUS2066() {
  Wire.begin(PIN_SDA, PIN_SCL);
  Wire.setClock(400000);

  if (!charOled.begin(&Wire, 0x3C, 20, 4)) {
    return false; // fallback to SSD1309
  }
  if (!charView.attach(&charOled)) {
    return false; // fallback to SSD1309
  }
  // simple boot splash (one-time). The view owns data thereafter.
  charView.splash("Type-D Wireless", "US2066 20x4", "Alt View Ready", "");
  return true;
}

void setup() {
  //Serial.begin(115200);

  LedStat::begin();
  LedStat::setStatus(LedStatus::Booting);
  WiFiMgr::begin();

  // Decide active display from portal pref
  useUS2066 = WiFiMgr::isUS2066Selected();

  if (useUS2066) {
    if (!initUS2066()) {
      useUS2066 = false; // fallback to SSD1309 below
    }
  }

  if (!useUS2066) {
    // ---- SSD1309 path ----
    Wire.begin(PIN_SDA, PIN_SCL);
    Wire.setClock(400000);

    pinMode(PIN_RST, OUTPUT);
    digitalWrite(PIN_RST, LOW);
    delay(20);
    digitalWrite(PIN_RST, HIGH);
    delay(250);

    u8g2.setI2CAddress(0x3D << 1);
    u8g2.begin();
    u8g2.setContrast(255);
    u8g2.setFlipMode(1); // use 0/1 as needed

    TypeDDisplay::begin(&u8g2);
    TypeDDisplay::setHoldTimes(15000, 5000);
  }

  Weather::begin();       // drive weather for BOTH displays (SSD1309 & US2066)

  TypeDUDP::begin();      // sockets bind on Wi-Fi connect and rebind on drops

  // Insignia emulator/runtime (shared across displays)
  Insignia::setServerBase("http://darkone83.myddns.me:8080/xbox, http://darkone83.myddns.me:8008/xbox/data");
  Insignia::setFlushCacheOnBoot(true);
  Insignia::setCacheLimits(32, 128*1024, 6UL*60*60*1000UL);
  Insignia::begin(/*debug=*/true);
}

void loop() {
  LedStat::loop();
  WiFiMgr::loop();

  // Drive the weather state machine regardless of display type.
  // (US2066 and SSD1309 views both read Weather::isReady()/get().)
  Weather::loop();

  // Always pump UDP first so display sees the freshest packet this tick
  TypeDUDP::loop();

  if (useUS2066) {
    // US2066 view ingests UDP (MAIN/EXT/EE), reads IP/RSSI, formats, and renders.
    charView.loop();   // <- parses MAIN/EXT/EE and renders pages (incl. weather page)
    Insignia::tick();  // <- tick AFTER view so Insignia reacts immediately if needed
  } else {
    // SSD1309 path (existing UI)
    TypeDDisplay::loop();
    Insignia::tick();  // SSD1309 timing unchanged
  }

  static bool mdnsStarted = false;
  const bool connected = WiFiMgr::isConnected();
  if (connected && !mdnsStarted) {
    if (MDNS.begin("typeddisp")) {
      mdnsStarted = true;
    }
  }
}

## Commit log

2025-09-13 Initial Upload
    [Shell.stl]
2025-09-18 Insignia Support
    Added insignia support, along with experimental support for the US2066 OLED display. Reworked OTA engine as well
    [Type_D_Wireless_Display.ino, dc_logo.h, display.cpp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]
2025-09-18 Name correction
    [US2066_BOM.xlsx]
2025-09-22 STL Updates
    [Shell Controller Port.stl, Shell Desktop.stl]
2025-09-23 PCB Updates
2025-09-24 Python Flashing script
    Quick script for flashing the Type D Wireless OLED firmware
2025-09-25 Conreoller port Shell for the US2066 OLED
    [US2066 Shell.stl]
2025-11-08 User Contributions
    S3 super mini pcb and aliexpress oled cases by MeTaLfAN
    [2.42 aliexpress screw case.3mf, 2.42 aliexpress screw case.stl]
2025-11-13 Added cases
    [aliexpress 2.42 oled slide version.3mf, aliexpress 2.42 oled slide version.stl]
